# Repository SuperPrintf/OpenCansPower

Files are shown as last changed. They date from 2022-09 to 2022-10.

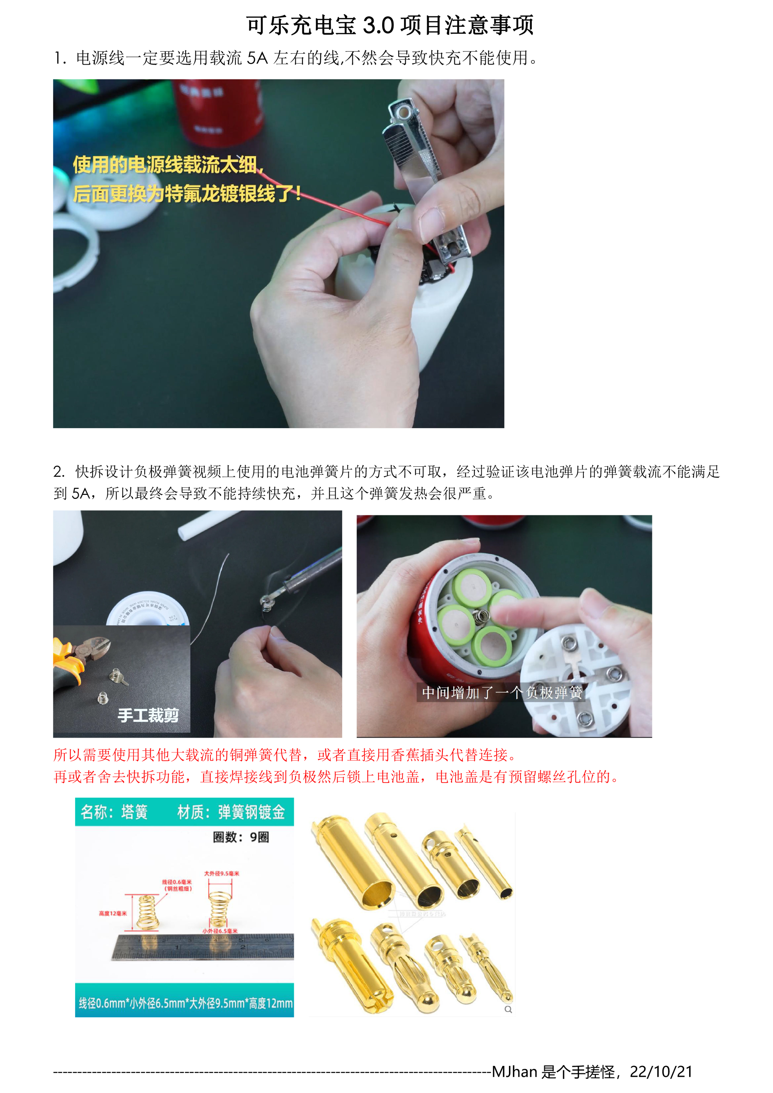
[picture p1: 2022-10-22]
可乐充电宝V3.0/可乐充电宝3.0注意事项.jpg

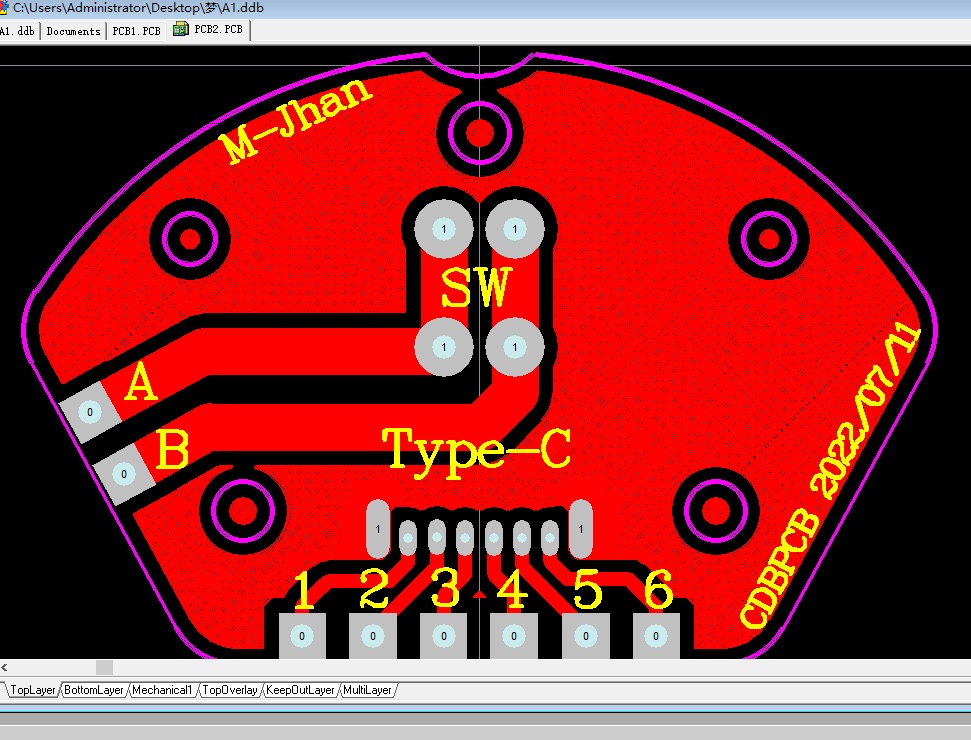
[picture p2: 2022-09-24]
原作者-2.0版本/PCB接线板/9a34f660-04ae-47a7-ad9b-f50996e17ae0.jpg

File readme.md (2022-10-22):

#易拉罐充电宝
##项目说明

#项目来源为B站up主 @MJhan是个手搓怪,本设计旨在为该项目增加快充解决方案

    -模型作者B站主页:https://space.bilibili.com/94128110
    -原版制作视频页面:https://www.bilibili.com/video/BV1NV4y1J7MQ
    -立创开源地址:https://oshwhub.com/big_big_A/ke-le-chong-dian-bao
  
#快充芯片采用英集芯制造的IP5358

    -该芯片支持双向QC2.0/3.0,双向PD2.0/3.0
    -最大输出规格 5V/3.1A 9V/2.0A 12V/1.5A
    -支持电池和PCB温度检测
    
#警告⚠️⚠️⚠️

    -芯片必须使用标准版，IP5358_BZ
    -网上很多卖家所出售的芯片版本不对，请务必仔细斟酌购买的店家
    -若购买到不对的芯片则有功能上的不同，可能会出现逻辑故障，甚至可能无法正常工作
    -在没有找到正规的购买渠道前建议不要复刻本项目
    -电池端峰值电流在5A以上，务必保证电池的载流能力
    -使用的连接线务必保证带载能力，否则会出现主板报错甚至高温烧板
  
有任何问题请在issues中提出

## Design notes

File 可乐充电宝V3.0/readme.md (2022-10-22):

#本文件夹由原作者整理本人上传
  
  -PCB部分仍在施工中，当前仅有PCB源文件以及Gerber文件

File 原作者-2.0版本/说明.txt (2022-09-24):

现有2.0版可乐充电宝，用到的充电板子不支持苹果协议，不支持快充，仅支持普通安卓设备充电。

C口充放电一体，最大输出5V2.4A。

制作过程，B站视频地址
1.0版本：https://www.bilibili.com/video/BV1NV4y1J7MQ/?vd_source=b11b66e38789937bda097098bc9ad359
2.0版本：https://www.bilibili.com/video/BV1NV4y1E72h/?vd_source=b11b66e38789937bda097098bc9ad359

-------------------------------------------------------------------------------来自：MJhan是个手搓怪

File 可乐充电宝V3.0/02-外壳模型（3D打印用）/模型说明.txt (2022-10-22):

3.0有两种版本，除了一个只支持5节21700电池外，功能没区别，自行二选一
建议使用18650和21700通用的版本

--------------------------------------------MJhan是个手搓怪------22/10/21----

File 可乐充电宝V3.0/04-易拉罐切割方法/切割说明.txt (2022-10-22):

UP使用的是得力的电磨切割的
用的是金刚砂小锯片，然后精细打磨用的是火石仔砂轮。

---------------------------------MJhan是个手搓怪-----22/10/21-----

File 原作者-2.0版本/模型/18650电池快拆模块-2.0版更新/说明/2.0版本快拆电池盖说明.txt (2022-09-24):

快拆电池盖可替换原来的螺丝版电池盖，可实现充电宝18650电池的拆卸
需要用到排针和排针母座，用于电池盖的线路连接，（具体款式可以看截图，或者自行选择其他的连接方式实现）

-------------------------------------------------------------------------------来自MJhan是个手搓怪

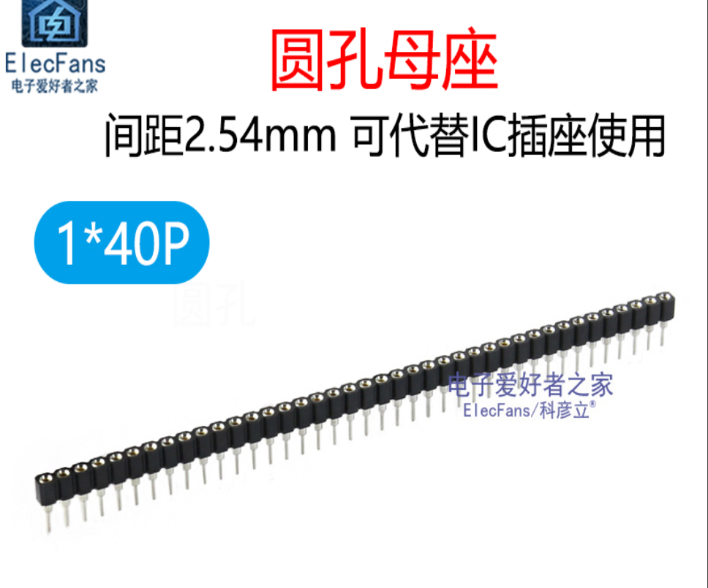
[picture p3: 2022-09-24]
原作者-2.0版本/模型/18650电池快拆模块-2.0版更新/说明/母座.png

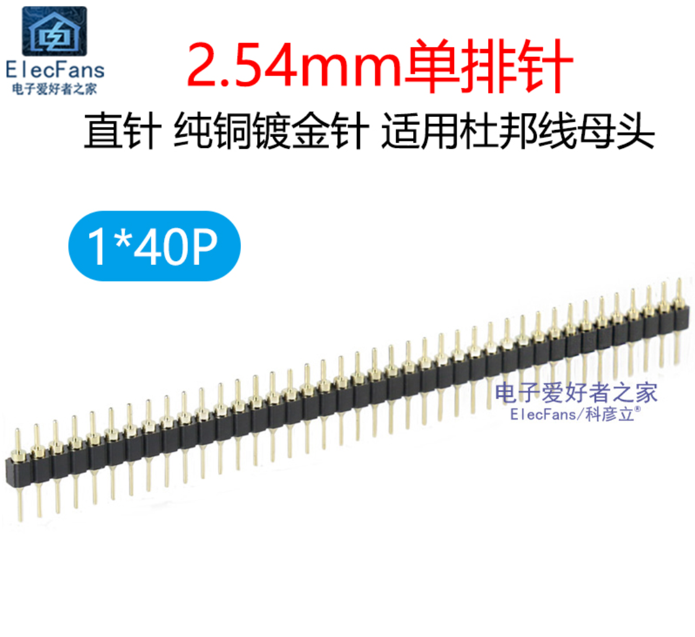
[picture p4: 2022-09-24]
原作者-2.0版本/模型/18650电池快拆模块-2.0版更新/说明/公头.jpg

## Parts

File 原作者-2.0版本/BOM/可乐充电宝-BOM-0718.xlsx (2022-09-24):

来自M-Jhan是个手搓怪 |  |  |  |  |  |  |  | 年 月 | 2022-07-18
 |  |  |  |  |  |  |  | 产品名 | 创意可乐充电宝 |  |  | 共 1页 第 1页
序 号 | 模具编号 | 零件名称/描述 | 图片 | 零件号 | 物料编号 | 数量 | 加工工艺简述 | 材料牌号 | 产品规格/mm | 单价（元） | 总价（元） | 备注
1 | \ | 1 |  | K1 | \ | 1 | 白色 | 树脂
2 | \ | 2 |  | K2 | \ | 1 | 银色 | 树脂
3 | \ | 3 |  | K3 | \ | 1 | 白色 | 树脂
4 | \ | 4 |  | K4 | \ | 1 | 白色 | 树脂
5 | \ | 5 |  | K5 | \ | 1 | 银色 | 树脂
6 | \ | 6 |  | K6 | \ | 1 | 银色 | 树脂
7 | \ | 7 |  | K7 | \ | 1 | 银色 | 树脂
8 | \ | 切割后的可乐罐 |  | K8 | \ | 1 | 原色 | 铝 | 可口可乐或百事可乐 |  |  | 需要切割，最好用电磨
9 | \ | PCB接线板 |  | B1 | \ | 1 |  | \ | 39*26*1mm |  |  | 提供pcb图纸，可以发嘉立创免费打样，记得选1mm的双面板
10 | \ | 5V充放电一体模块 |  | B2 | \ | 1 |  | \ | 20**16.5mm （黑色焊线款） |  |  | https://item.taobao.com/item.htm?spm=a1z10.1-c-s.w4004-21865873505.2.9f842579hmMCZn&id=679750658331
11 | \ | 18650锂电池 |  | B3 | \ | 5 |  | \ | 18650平头款 |  |  | 买5个平头款的，容量可选
12 | \ | 电池弹簧片 |  | B4 | \ | 5对 |  | \ | 12.1*14mm（小款） |  |  | https://item.taobao.com/item.htm?spm=a1z09.2.0.0.6cc02e8drCWnYK&id=644026575875&_u=i1mhr4dk76f1
13 | \ | Type-C母座 |  | B5 | \ | 1 |  | \ | 选6.8H，立式插脚 |  |  | https://item.taobao.com/item.htm?spm=a1z09.2.0.0.6cc02e8drCWnYK&id=602136520062&_u=i1mhr4dk0ee8
14 | \ | 轻触开关 |  | B6 | \ | 1 |  | \ | 4.5*4.5*5mm |  |  | https://detail.tmall.com/item.htm?id=583250070588&_u=i1mhr4dk3740&skuId=3920120796511
15 | \ | 导光柱 |  | B7 | \ | 4 |  | \ | 1.5*10mm |  |  | https://detail.tmall.com/item.htm?id=643255987941&spm=a1z09.2.0.0.6cc02e8drCWnYK&_u=i1mhr4dkd284
16 | \ | C口防尘塞 |  | B8 | \ | 1 |  | \ | Type-c口专用
17 | \ | M2.3*6 |  | L1 | \ | 18 |  | 306 | M2.3*6 |  |  | 圆头平尾自攻螺丝
18 | \ | M1.4*8 |  | L2 | \ | 6 |  | 306 | M1.4*8 |  |  | 圆头平尾自攻螺丝

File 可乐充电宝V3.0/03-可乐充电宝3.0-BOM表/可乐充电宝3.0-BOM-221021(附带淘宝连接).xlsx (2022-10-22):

来自：M-Jhan是个手搓怪 |  |  |  |  |  |  |  | 年 月 | 2022-10-22
 |  |  |  |  |  |  |  | 产品名 | 创意可乐充电宝3.0 |  |  | 共 1页 第 1页
序 号 | 模具编号 | 零件名称/描述 | 图片 | 零件号 | 物料编号 | 数量 | 加工工艺简述 | 材料牌号 | 产品规格/mm | 单价（元） | 总价（元） | 备注
1 | \ | 盖子 |  | K1 | \ | 1 | 白色 | 树脂 | 局部喷漆 |  |  | 3D打印可以去嘉立创
2 | \ | 电池舱 |  | K2 | \ | 1 | 白色 | 树脂 |  |  |  | 3D打印可以去嘉立创
3 | \ | 电池盖 |  | K3 | \ | 1 | 白色 | 树脂 |  |  |  | 3D打印可以去嘉立创
4 | \ | 固定环 |  | K4 | \ | 1 | 银色 | 树脂 | 局部喷漆 |  |  | 3D打印可以去嘉立创
5 | \ | 底盖 |  | K5 | \ | 1 | 银色 | 树脂 | 局部喷漆 |  |  | 3D打印可以去嘉立创
6 | \ | 负极固定柱 |  | K6 | \ | 1 | 白色 | 树脂 |  |  |  | 3D打印可以去嘉立创
7 | \ | 按键 |  | K7 | \ | 1 | 银色 | 树脂 | 局部喷漆 |  |  | 3D打印可以去嘉立创
8 | \ | 18转21电池环 |  | K8 | \ | 4 | 白色 | 树脂 |  |  |  | 3D打印可以去嘉立创
9 | \ | 易拉罐 |  | B1 | \ | 1 | 原色 | 铝 | 可口可乐或百事可乐 |  |  | 需要切割，最好用电磨
10 | \ | 快充电源主板 |  | B2 | \ | 1 |  | \ | φ45*1mm |  |  | 需要自己焊接板子，嘉立创免费打样，板厚选1mm。立创商城元器件配单,或者自行淘宝.
11 | \ | 18650/21700电池 |  | B3 | \ | 4 |  | \ | 18650平头款 21700平头款 |  |  | 两种电池二选一，买4个平头款的，容量可选
12 | \ | 电池弹簧片 |  | B4 | \ | 8个带弹簧的弹片 |  | \ | 12.1*14mm（小款） |  |  | https://item.taobao.com/item.htm?spm=a1z09.2.0.0.6cc02e8drCWnYK&id=644026575875&_u=i1mhr4dk76f1
13 | \ | 电源线 |  | B5 | \ | 2 |  | \ | 选用载流5A左右的线 |  |  | https://item.taobao.com/item.htm?spm=a1z09.2.0.0.3af82e8dTcSecY&id=649409815526&_u=m1mhr4dkc476
14 | \ | 负极快拆香蕉插头 |  | B6 | \ | 1对 |  | \ | 4mm公母头 | 二选一，用香蕉插头载流就肯定够用，用黄铜弹簧载流可能有待验证，反正载流需要5A左右。（UP视频上面用电池弹簧片裁剪的弹簧载流就不够，后面发现快充不能长时间持续。） |  | https://detail.tmall.com/item.htm?id=675199775794&skuId=4850828084439
15 | \ | 负极快拆黄铜弹簧 |  | B7 | \ | 1 |  | \ | 0.6*6.5*9.5*H12 |  |  | https://item.taobao.com/item.htm?spm=a1z0d.6639537/tb.1997196601.3.4ff67484Rc0WIV&id=665811044259
16 | \ | 导光柱 |  | B8 | \ | 4 |  | \ | 1.5*6mm |  |  | https://detail.tmall.com/item.htm?id=643255987941&spm=a1z09.2.0.0.6cc02e8drCWnYK&_u=i1mhr4dkd284
17 | \ | C口防尘塞 |  | B9 | \ | 1 |  | \ | Type-c口专用 |  |  | 防尘用
18 | \ | M2.3*6 |  | L1 | \ | 8 |  | 306 | M2.3*6 |  |  | 圆头平尾自攻螺丝
19 | \ | M1.4*6 |  | L2 | \ | 6 |  | 306 | M1.4*6 |  |  | 圆头平尾自攻螺丝

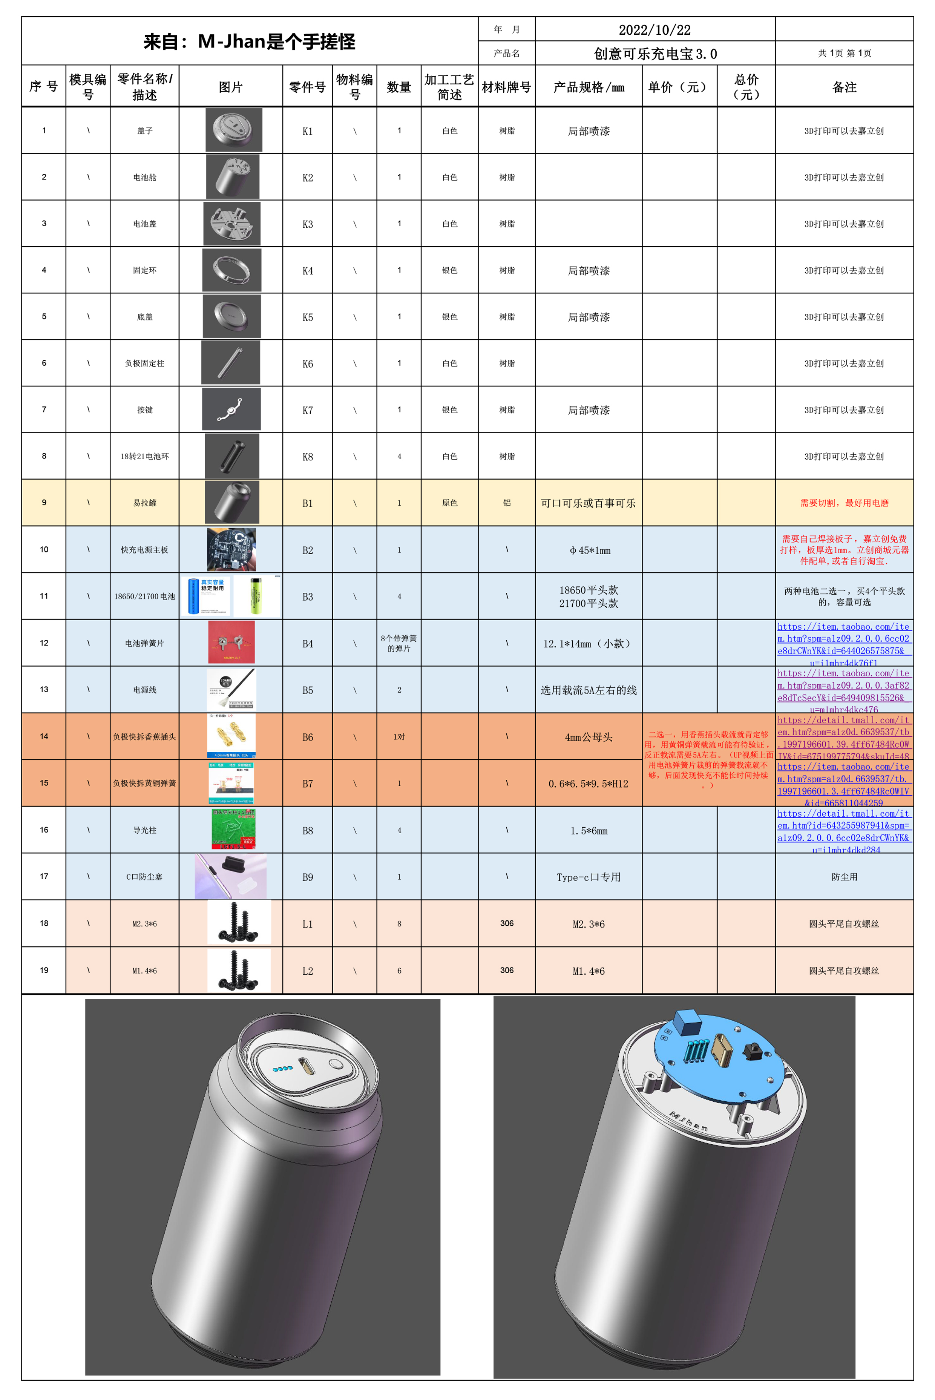
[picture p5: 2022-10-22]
可乐充电宝V3.0/03-可乐充电宝3.0-BOM表/可乐充电宝3.0-BOM-221021.jpg

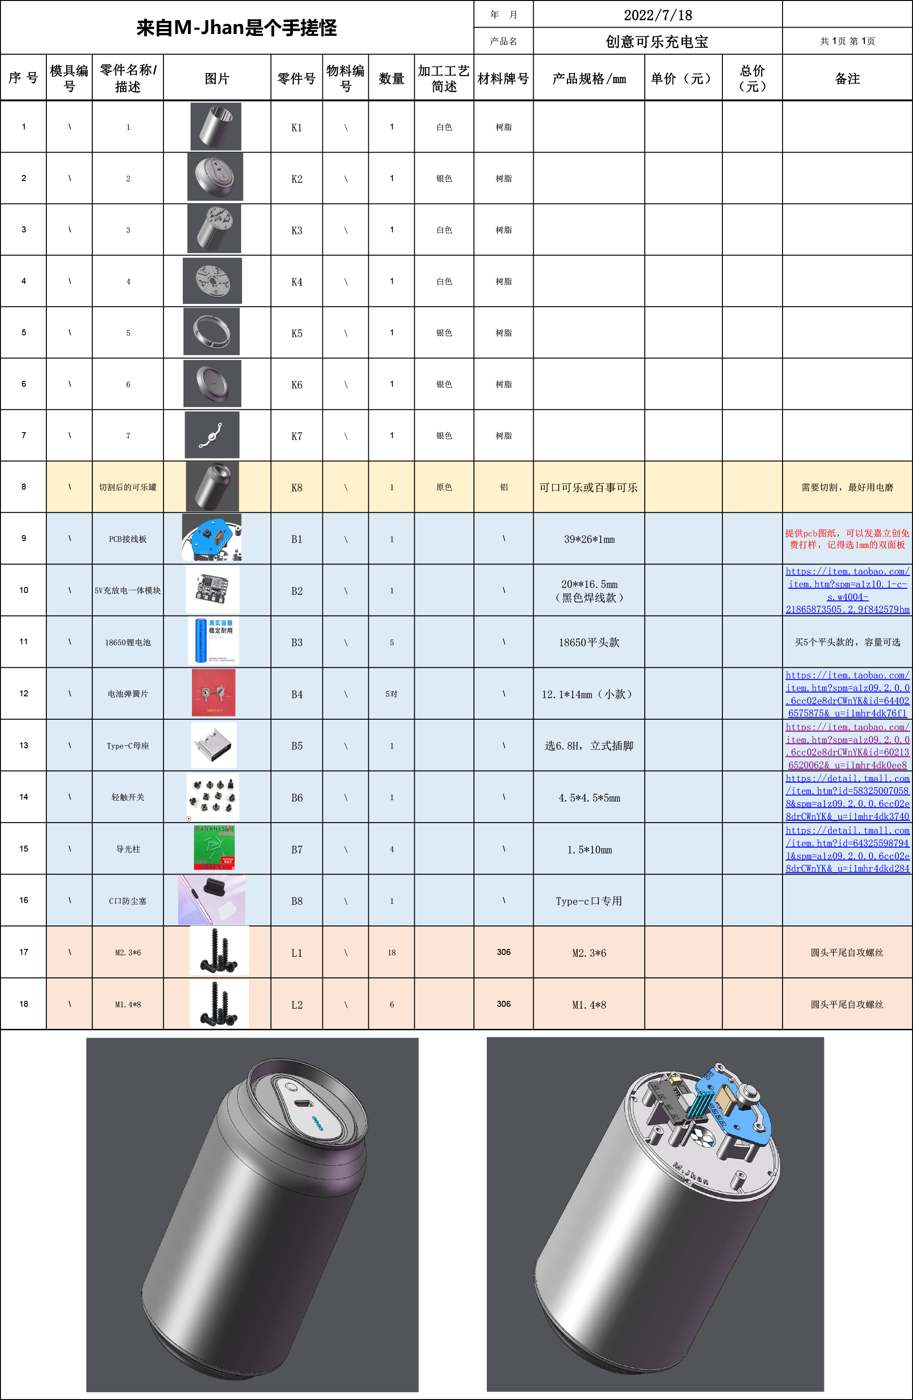
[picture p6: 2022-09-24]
原作者-2.0版本/BOM/可乐充电宝-BOM-0718-1 拷贝.png

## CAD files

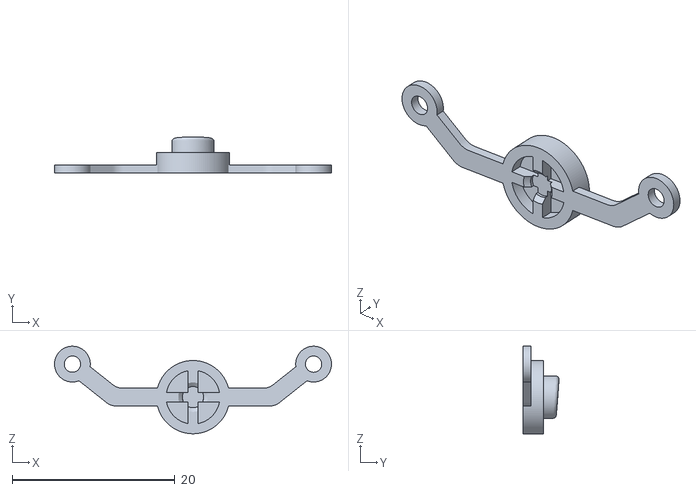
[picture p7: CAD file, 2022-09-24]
原作者-2.0版本/模型/007.STL
34.0 x 4.43 x 10.8

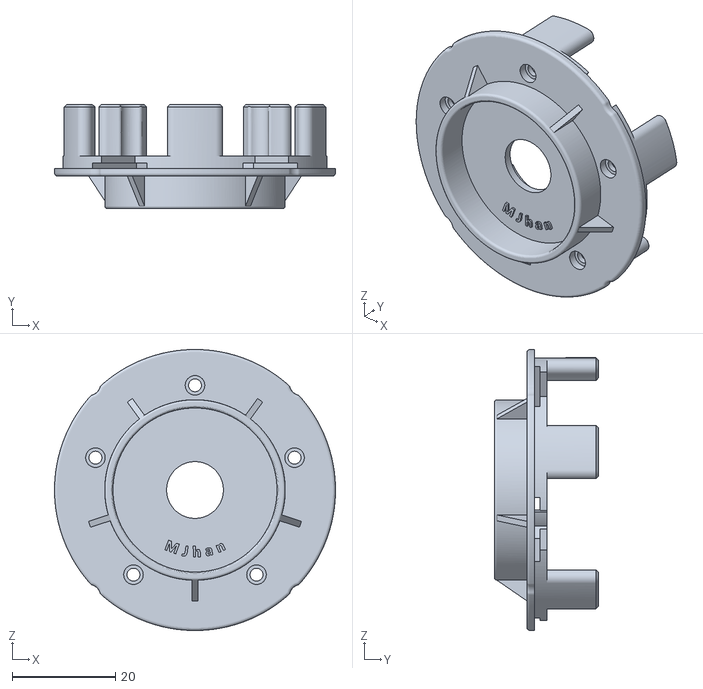
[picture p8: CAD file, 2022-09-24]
原作者-2.0版本/模型/18650电池快拆模块-2.0版更新/模型/2.0更新-快拆电池盖.STL
54.5 x 20.2 x 54.5

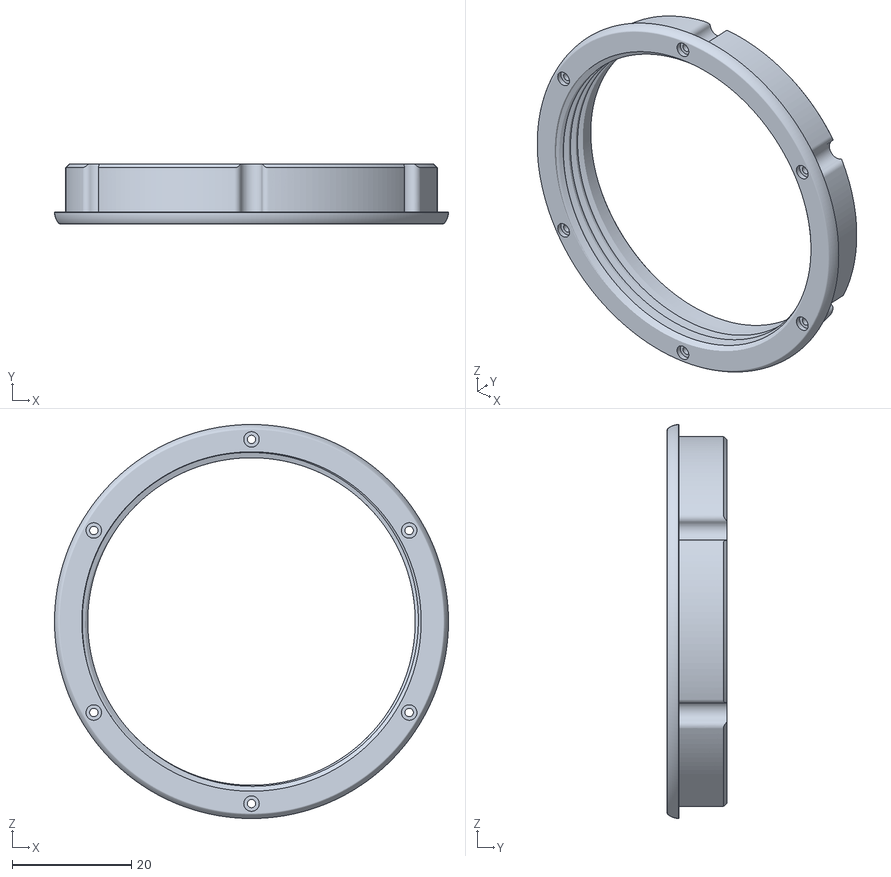
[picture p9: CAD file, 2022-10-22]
可乐充电宝V3.0/02-外壳模型（3D打印用）/可乐充电宝3.0-模型（18650x5单独版）/固定环.STL
66.0 x 10.00 x 66.0

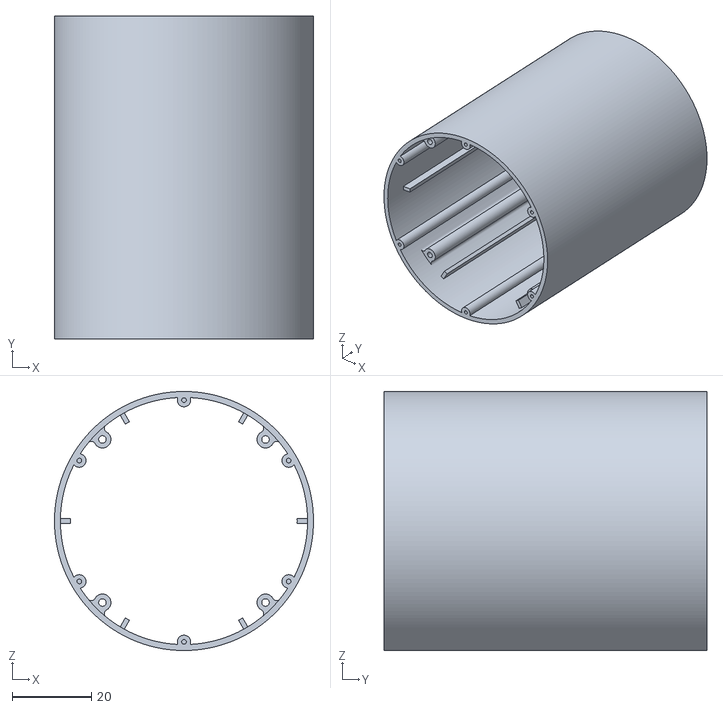
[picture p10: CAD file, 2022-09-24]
原作者-2.0版本/模型/001.STL
65.4 x 81.5 x 65.4

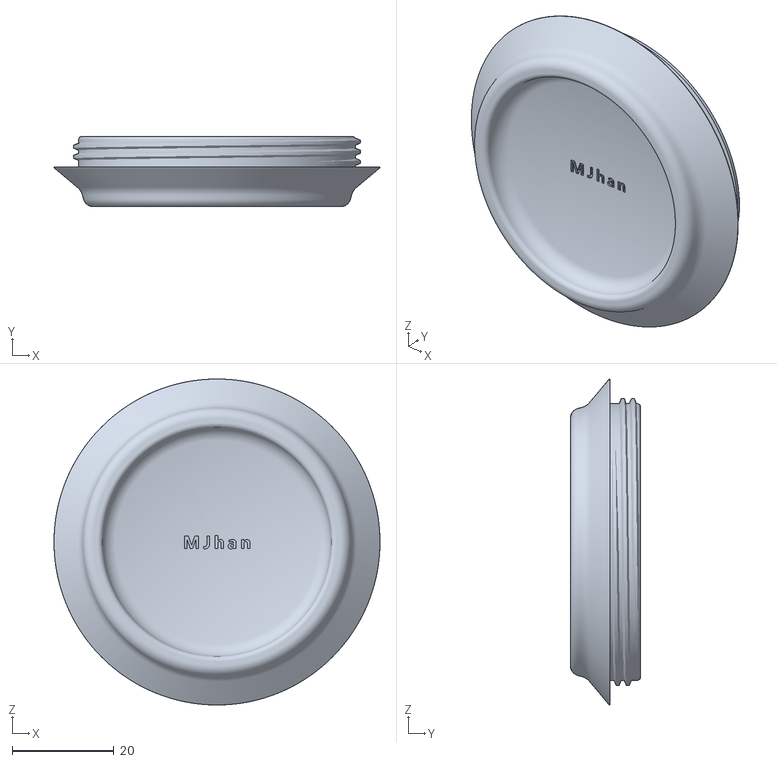
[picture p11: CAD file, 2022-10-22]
可乐充电宝V3.0/02-外壳模型（3D打印用）/可乐充电宝3.0-模型（18650x4-21700x4通用版）/底盖.STL
64.2 x 13.8 x 64.2

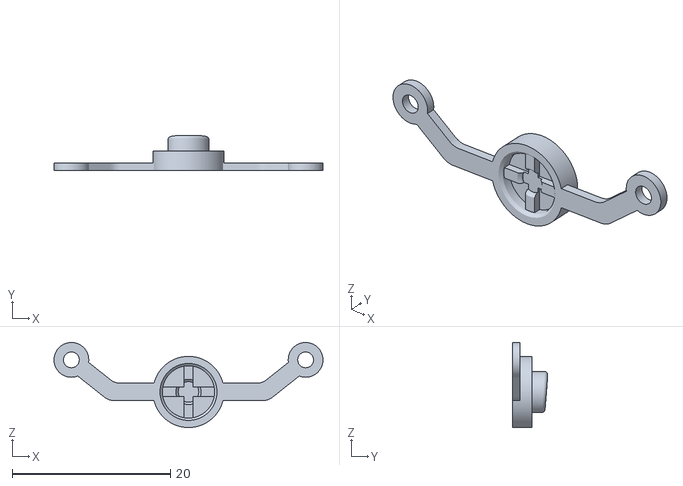
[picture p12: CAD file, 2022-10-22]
可乐充电宝V3.0/02-外壳模型（3D打印用）/可乐充电宝3.0-模型（18650x5单独版）/按键.STL
34.0 x 4.48 x 10.8

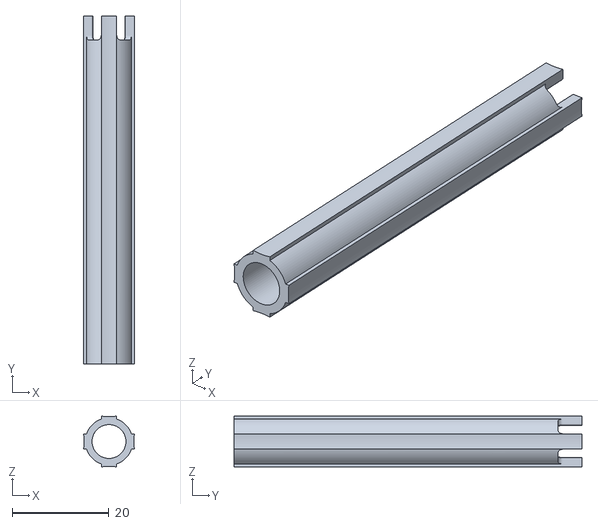
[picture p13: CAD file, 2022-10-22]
可乐充电宝V3.0/02-外壳模型（3D打印用）/可乐充电宝3.0-模型（18650x4-21700x4通用版）/负极固定柱-2.STL
10.5 x 72.0 x 10.5

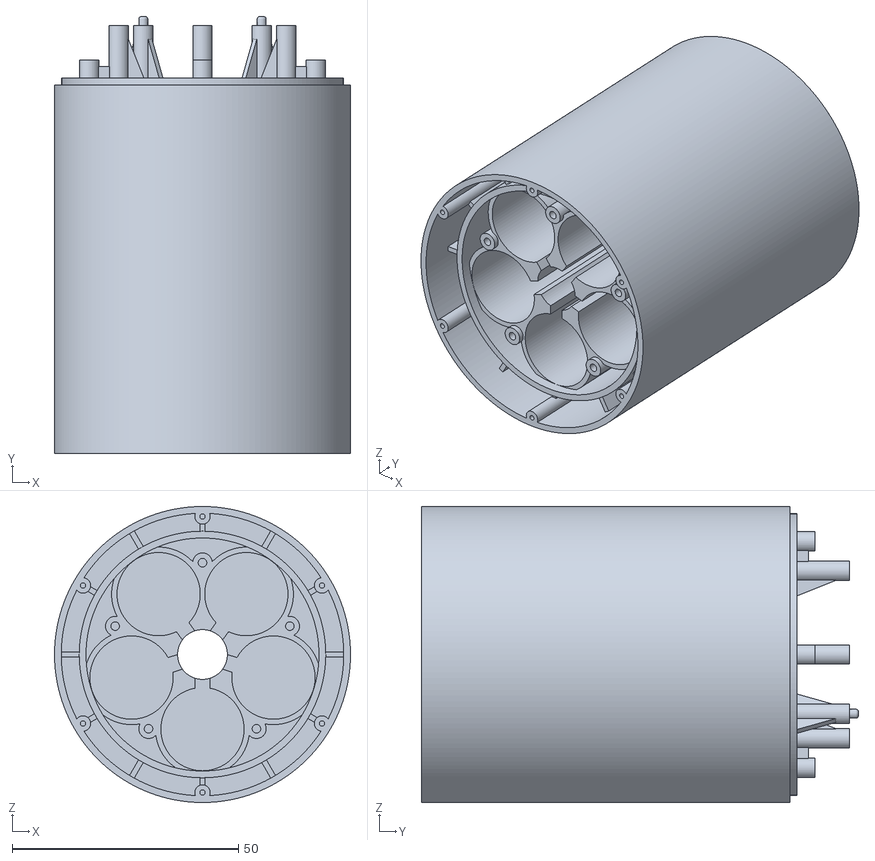
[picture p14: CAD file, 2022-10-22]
可乐充电宝V3.0/02-外壳模型（3D打印用）/可乐充电宝3.0-模型（18650x5单独版）/电池舱-1.STL
65.4 x 96.6 x 65.4

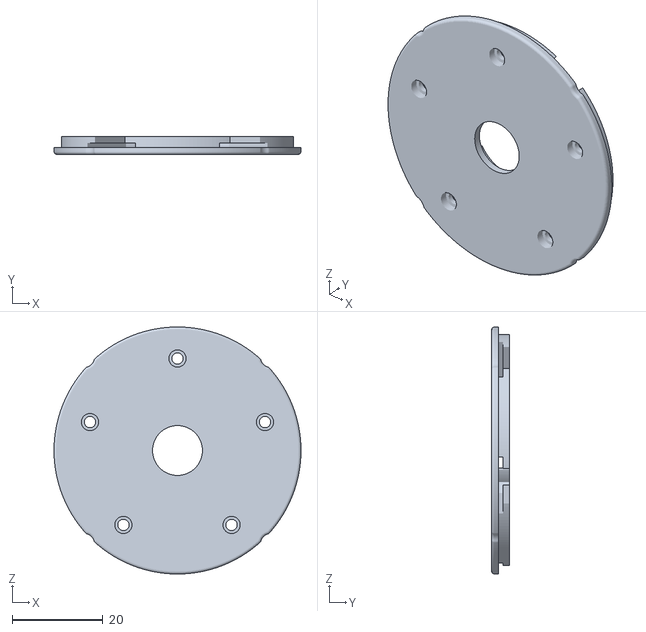
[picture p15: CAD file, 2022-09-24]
原作者-2.0版本/模型/004.STL
54.5 x 3.90 x 54.5

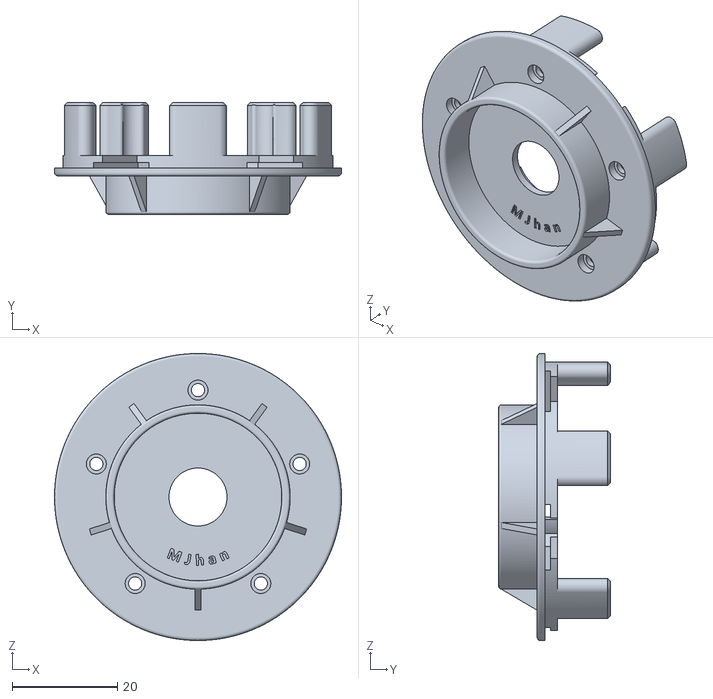
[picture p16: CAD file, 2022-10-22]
可乐充电宝V3.0/02-外壳模型（3D打印用）/可乐充电宝3.0-模型（18650x5单独版）/电池盖-1.STL
54.5 x 21.2 x 54.5

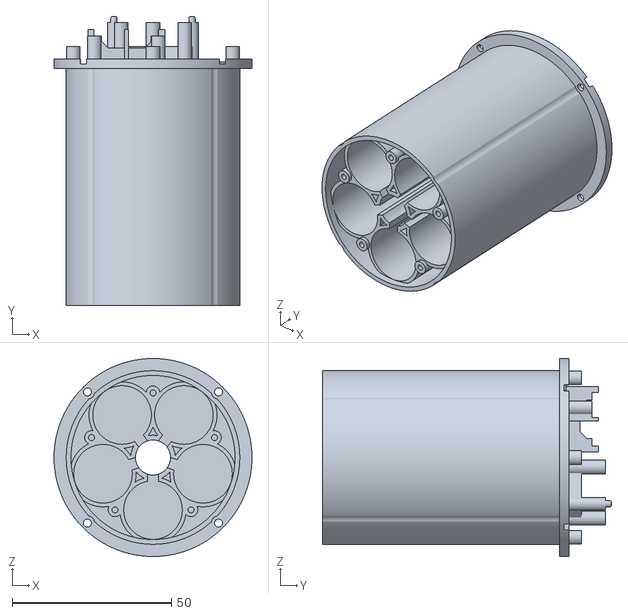
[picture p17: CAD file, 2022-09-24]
原作者-2.0版本/模型/003.STL
62.2 x 90.8 x 62.2

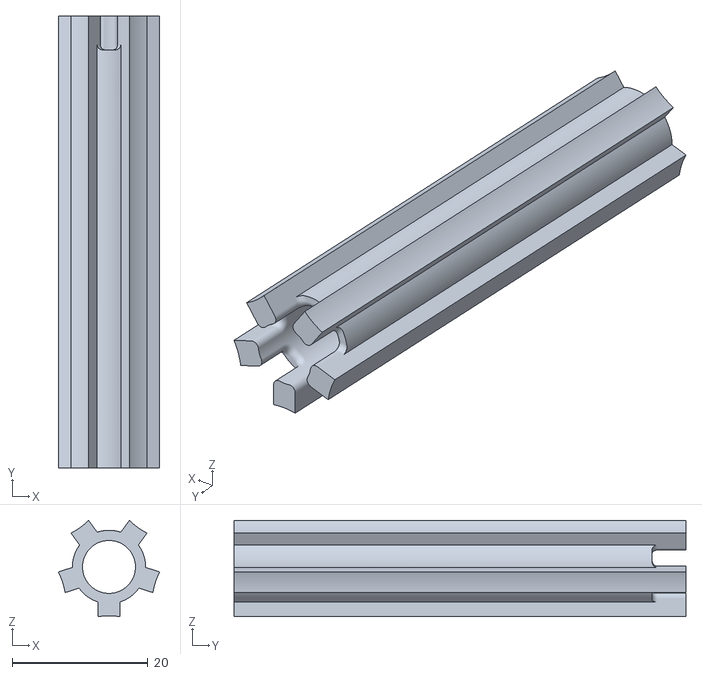
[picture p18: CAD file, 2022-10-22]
可乐充电宝V3.0/02-外壳模型（3D打印用）/可乐充电宝3.0-模型（18650x5单独版）/负极固定柱-1.STL
14.9 x 66.6 x 14.2

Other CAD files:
可乐充电宝V3.0/02-外壳模型（3D打印用）/可乐充电宝3.0-模型（18650x4-21700x4通用版）/电池盖-2.STL
原作者-2.0版本/模型/006.STL
可乐充电宝V3.0/02-外壳模型（3D打印用）/可乐充电宝3.0-模型（18650x4-21700x4通用版）/固定环.STL
原作者-2.0版本/模型/005.STL
可乐充电宝V3.0/02-外壳模型（3D打印用）/可乐充电宝3.0-模型（18650x4-21700x4通用版）/电池舱-2.STL
可乐充电宝V3.0/02-外壳模型（3D打印用）/可乐充电宝3.0-模型（18650x4-21700x4通用版）/18转21电池环.STL
可乐充电宝V3.0/02-外壳模型（3D打印用）/可乐充电宝3.0-模型（18650x5单独版）/底盖.STL

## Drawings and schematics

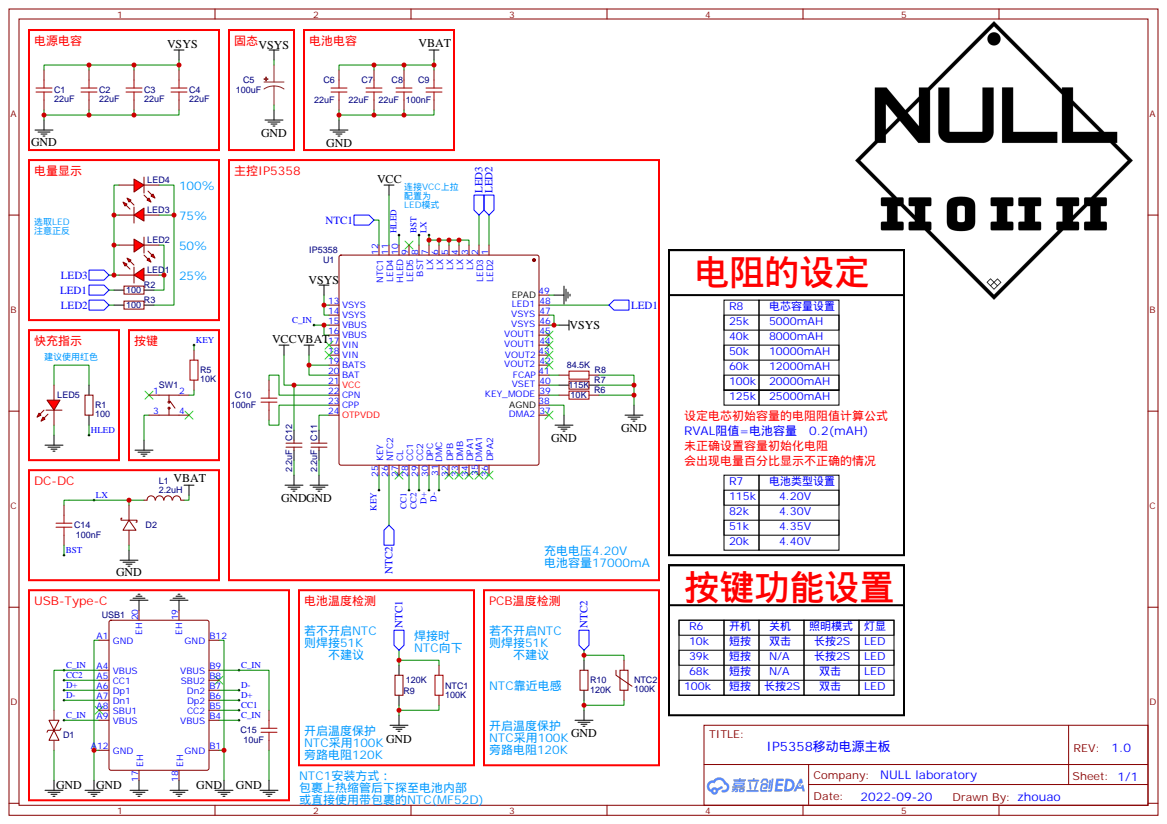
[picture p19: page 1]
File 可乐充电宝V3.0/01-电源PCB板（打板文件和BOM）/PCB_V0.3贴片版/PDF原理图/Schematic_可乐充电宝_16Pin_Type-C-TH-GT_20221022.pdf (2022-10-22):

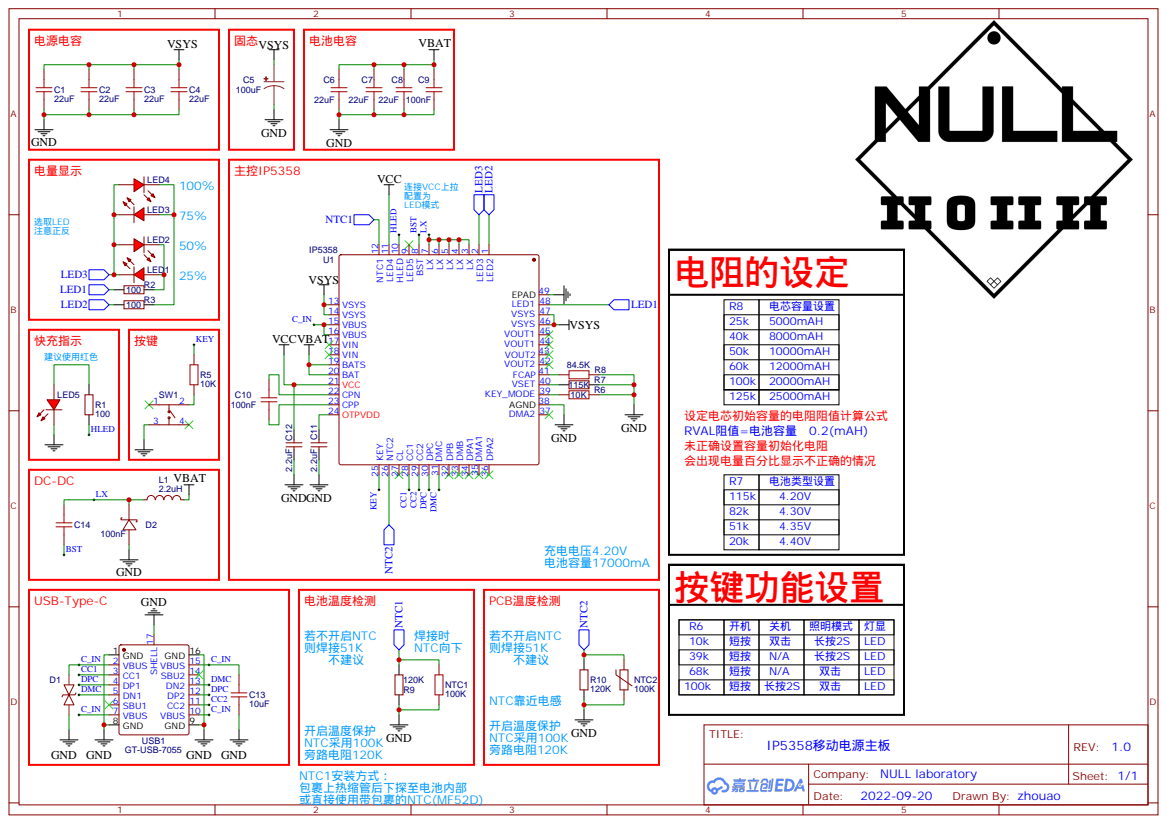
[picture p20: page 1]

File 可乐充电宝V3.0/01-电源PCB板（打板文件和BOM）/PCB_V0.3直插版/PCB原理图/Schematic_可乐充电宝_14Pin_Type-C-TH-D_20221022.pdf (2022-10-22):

100%

## 主控IP5358
